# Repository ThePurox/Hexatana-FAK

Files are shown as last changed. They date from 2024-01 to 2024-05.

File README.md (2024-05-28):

# Hexatana
Hexatana is a 36 katana-inspired keyboard designed around [hexagonal keycaps](https://hw.s-ol.nu/HEX-keycaps/), which require Choc v1 switches.
It uses the CH552T controller and [FAK firmware](https://github.com/semickolon/fak).
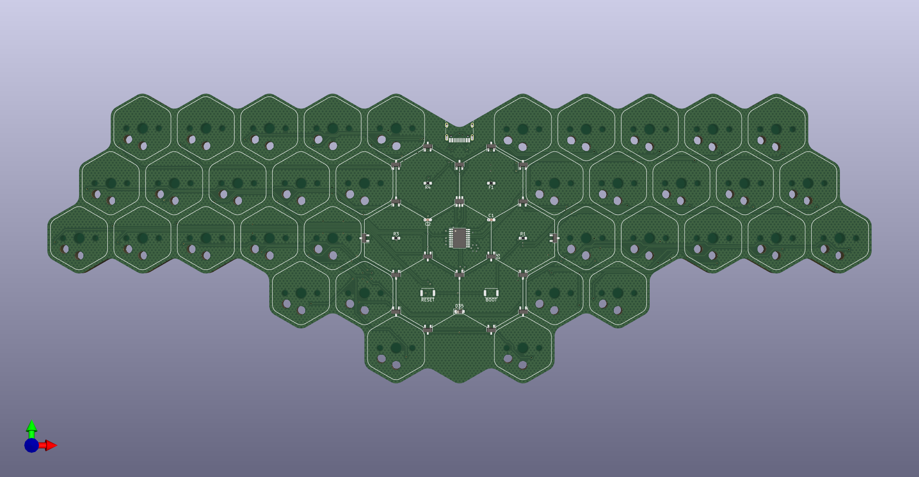
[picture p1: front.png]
front view of keyboard

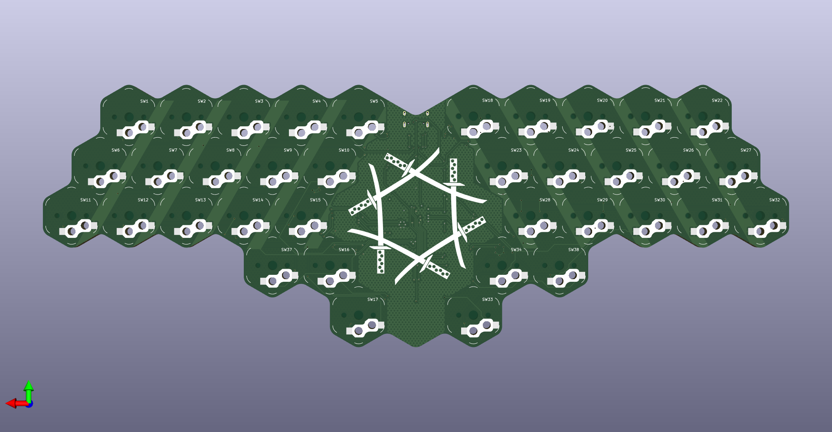
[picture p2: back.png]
back view of keyboard

The electronic design is derived from the [MIAO MCU board](https://github.com/kilipan/miao).

# Buildguide
For soldering everything have a look at the [interactive bill of materials](bom/ibom.html).

After soldering everything plug in the switches into the hot swap sockets and install the keycaps.

Now it is time to configure the firmware.
All config-files needed for an extremely basic firmware to test whether all the keys work can be found [here](https://github.com/ThePurox/fak-config/tree/main/keyboards/hexatana)

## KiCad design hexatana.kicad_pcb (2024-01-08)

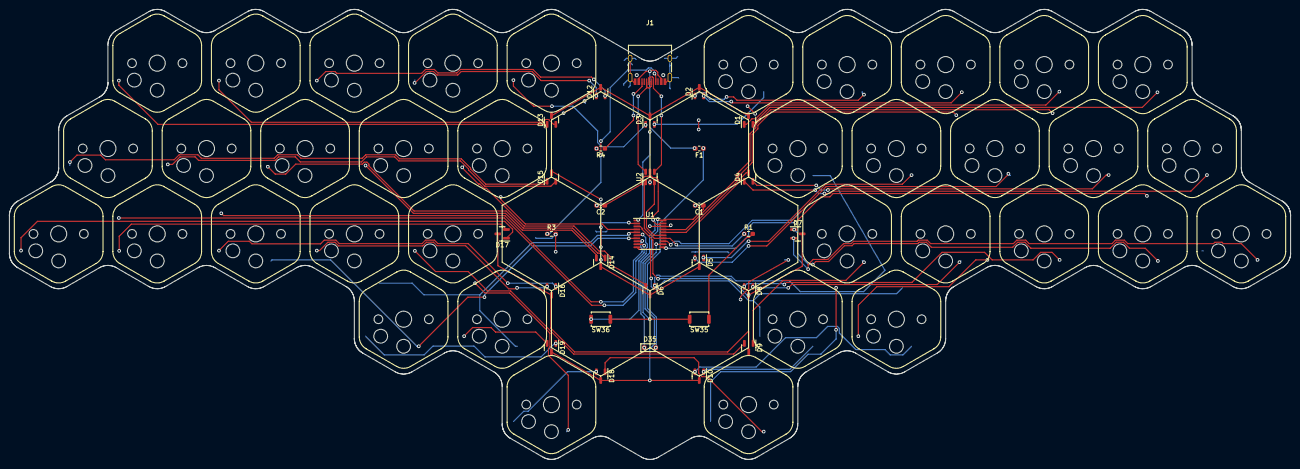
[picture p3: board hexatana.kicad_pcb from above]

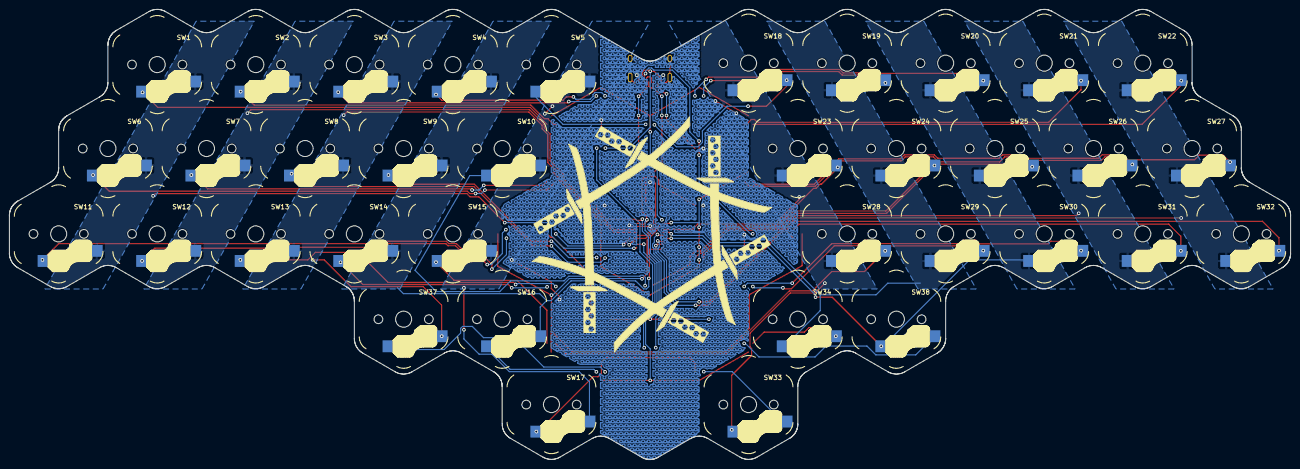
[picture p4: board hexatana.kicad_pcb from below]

Board: 2 copper layers, 279.5 x 98.2 mm, 66 parts (36 on the bottom side), 63 nets.

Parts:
C1, C2: 100nF; C_0603_1608Metric_Pad1.08x0.95mm_HandSolder
D1, D2, D3, D4, D5, D6, D7, D8, D9, D10, D12, D13, D14, D15, D16, D17, D18, D19: BAV70_Small; SOT-23
D35: PMEG2010EA; D_SOD-323_HandSoldering
F1: 500mA; Fuse_0603_1608Metric_Pad1.05x0.95mm_HandSolder
J1: USB_C_Receptacle_USB2.0; USB_C_Receptacle_HRO_TYPE-C-31-M-12
R1: 10k; R_0603_1608Metric_Pad0.98x0.95mm_HandSolder
R3, R4: 5.1k; R_0603_1608Metric_Pad0.98x0.95mm_HandSolder
SW1, SW2, SW3, SW4, SW5, SW6, SW7, SW8, SW9, SW10, SW11, SW12, SW13, SW14, SW15, SW16, SW17, SW18, SW19, SW20, SW21, SW22, SW23, SW24, SW25, SW26, SW27, SW28, SW29, SW30, SW31, SW32, SW33, SW34, SW37, SW38: SW_Push; PG1350_hotswap
SW35: BOOT; SW_Push_SPST_NO_Alps_SKRK
SW36: RESET; SW_Push_SPST_NO_Alps_SKRK
U1: TSSOP-20_4.4x6.5mm_P0.65mm
U2: USBLC6-2SC6; SOT-23-6

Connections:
+3.3V: C1.1, SW35.2, SW36.2, U1.20 (V33)
BOOT: R1.2, SW35.1
CC1: J1.A5 (CC1), R3.1
CC2: J1.B5 (CC2), R4.1
GND: C1.2, C2.2, J1.A1 (GND), J1.A12 (GND), J1.B1 (GND), J1.B12 (GND), J1.S1 (SHIELD), R3.2, R4.2, U1.18 (GND), U2.2 (GND)
unnamed: D1.1 (A1), SW2.2
unnamed: D1.2 (A2), SW1.2
unnamed: D2.1 (A1), SW4.2
unnamed: D2.2 (A2), SW3.2
unnamed: D3.1 (A1), SW18.1
unnamed: D3.2 (A2), SW5.2
unnamed: D4.1 (A1), SW6.2
unnamed: D4.2 (A2), SW7.2
unnamed: D5.1 (A1), SW9.2
unnamed: D5.2 (A2), SW8.2
unnamed: D6.1 (A1), SW10.2
unnamed: D6.2 (A2), SW23.1
unnamed: D7.1 (A1), SW12.2
unnamed: D7.2 (A2), SW11.2
unnamed: D8.1 (A1), SW14.2
unnamed: D8.2 (A2), SW13.2
unnamed: D9.1 (A1), SW15.2
unnamed: D9.2 (A2), SW28.1
unnamed: D10.1 (A1), SW16.2
unnamed: D10.2 (A2), SW37.2
unnamed: D12.1 (A1), SW19.1
unnamed: D12.2 (A2), SW20.1
unnamed: D13.1 (A1), SW22.1
unnamed: D13.2 (A2), SW21.1
unnamed: D14.1 (A1), SW25.1
unnamed: D14.2 (A2), SW24.1
unnamed: D15.1 (A1), SW27.1
unnamed: D15.2 (A2), SW26.1
unnamed: D16.1 (A1), SW30.1
unnamed: D16.2 (A2), SW29.1
unnamed: D17.1 (A1), SW32.1
unnamed: D17.2 (A2), SW31.1
unnamed: D18.1 (A1), SW17.2
unnamed: D18.2 (A2), SW33.1
unnamed: D19.1 (A1), SW38.1
unnamed: D19.2 (A2), SW34.1
unnamed: D35.2 (A), F1.1
PORT+: J1.A6 (D+), J1.B6 (D+), U2.6 (I/O1)
PORT-: J1.A7 (D-), J1.B7 (D-), U2.4 (I/O2)
RST: SW36.1, U1.6 (RST)
UDM: U1.15 (P3.7), U2.3 (I/O2)
UDP: R1.1, U1.14 (P3.6), U2.1 (I/O1)
VBUS: F1.2, J1.A4 (VBUS), J1.A9 (VBUS), J1.B4 (VBUS), J1.B9 (VBUS)
VCC: C2.1, D35.1 (K), U1.19 (VCC), U2.5 (VBUS)
col1: SW1.1, SW6.1, SW11.1, U1.11 (P3.3)
col2: SW2.1, SW7.1, SW12.1, U1.17 (P1.2)
col3: SW3.1, SW8.1, SW13.1, SW37.1, U1.16 (P1.3)
col4: SW4.1, SW9.1, SW14.1, SW16.1, U1.10 (P3.0)
col5: SW5.1, SW10.1, SW15.1, SW17.1, U1.13 (P3.5)
col6: SW18.2, SW23.2, SW28.2, SW33.2, U1.4 (P1.6)
col7: SW19.2, SW24.2, SW29.2, SW34.2, U1.5 (P1.7)
col8: SW20.2, SW25.2, SW30.2, SW38.2, U1.7 (P1.0)
col9: SW21.2, SW26.2, SW31.2, U1.8 (P1.1)
col10: SW22.2, SW27.2, SW32.2, U1.9 (P3.1)
row1: D1.3 (K), D2.3 (K), D3.3 (K), D12.3 (K), D13.3 (K), U1.1 (P3.2)
row2: D4.3 (K), D5.3 (K), D6.3 (K), D14.3 (K), D15.3 (K), U1.2 (P1.4)
row3: D7.3 (K), D8.3 (K), D9.3 (K), D16.3 (K), D17.3 (K), U1.3 (P1.5)
row4: D10.3 (K), D18.3 (K), D19.3 (K), U1.12 (P3.4)

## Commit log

2024-01-07 v 0.1
    [hexatana.kicad_pcb, hexatana.kicad_sch]
2024-01-08 fixed missing col5 on mcu
    [hexatana.kicad_pcb, hexatana.kicad_sch]
